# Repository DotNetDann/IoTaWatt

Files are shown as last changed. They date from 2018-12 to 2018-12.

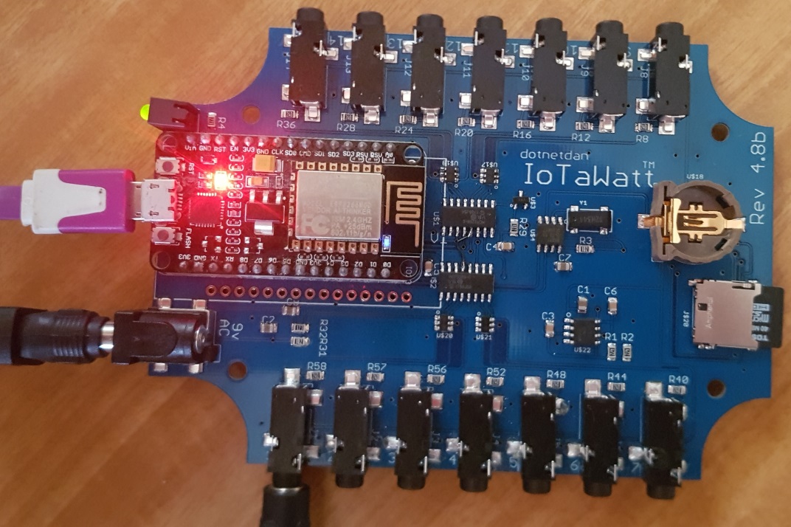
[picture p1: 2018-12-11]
PCB.jpg

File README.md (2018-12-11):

### IotaWatt 4.8

This is forked from [boblemaire's github](https://github.com/boblemaire/IoTaWatt)

Changes to main repository:
* Changed the PCB to fit a ESP32 (In case one day) and to get the silk screen to show in the generated gurbers
* Created a sample config to integrate with HomeAssistant. This integration uses the rest sensor in HA and query’s the JSON data every few seconds. You are able to get all your channels as well as any output calculated values you have setup.

NOTE: The PCB s using a 1v refrence shunt so you need to edit the config.txt to add a refvolts item under the device.

>{
>	"device": {
>		"refvolts": 1.0,

Go to the main repository as boblemaire is doing some amazing work with this project.

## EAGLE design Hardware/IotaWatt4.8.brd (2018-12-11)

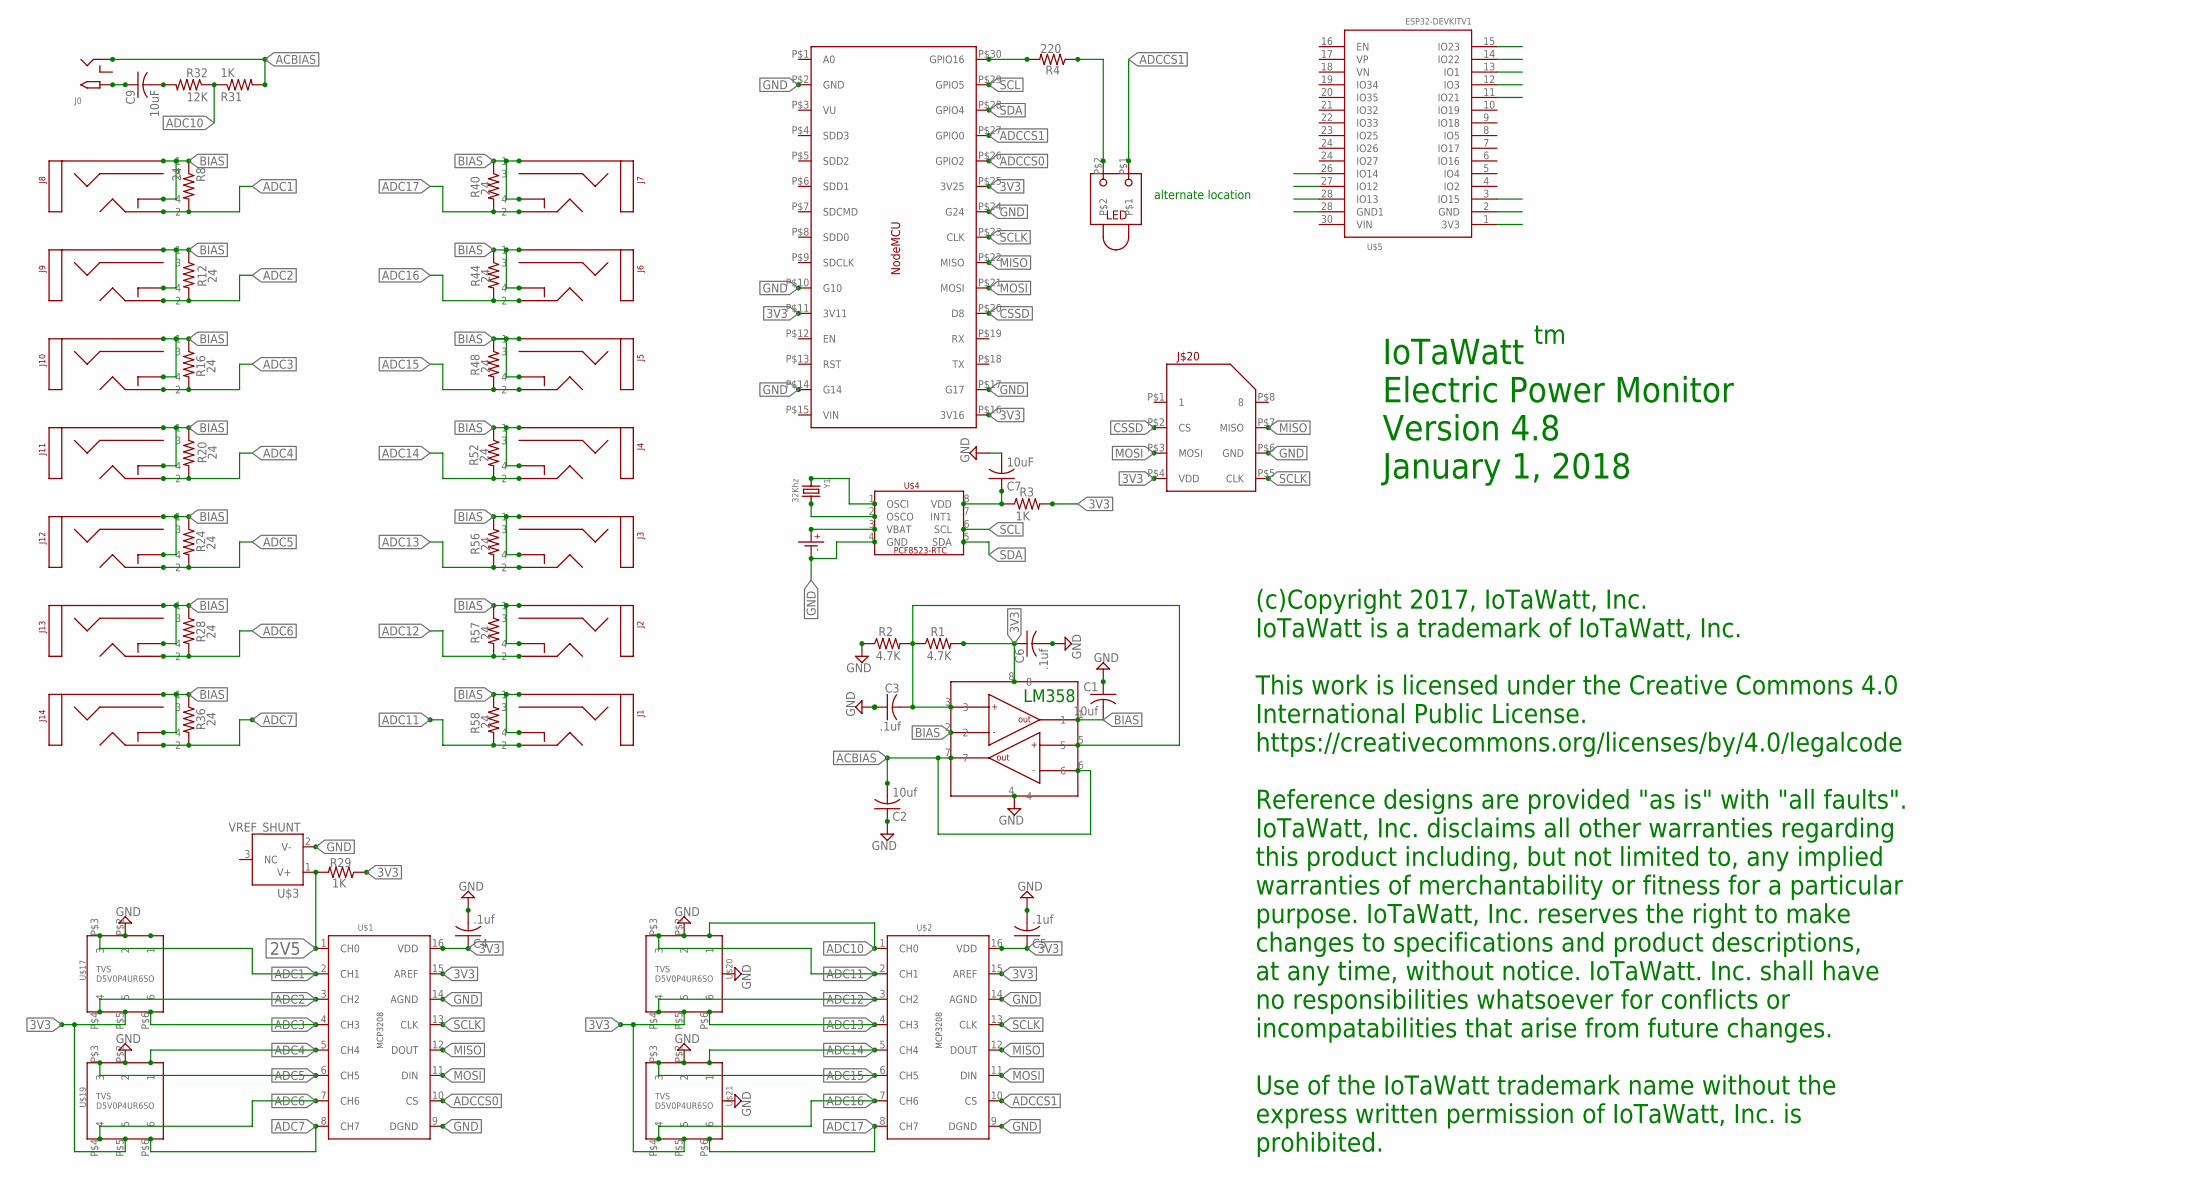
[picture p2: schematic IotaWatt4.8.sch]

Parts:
C1, C2: 10uf; C0805
C3, C4, C5, C6: .1uf; C0805
C7, C9: 10uF; C0805
J0: 2.1MMJACKSMT; DCJACK_2MM_SMT
J1, J2, J3, J4, J5, J6, J7, J8, J9, J10, J11, J12, J13, J14: STEREO_SMD; STEREO_SMT
J$20: MICROSD_PUSH/PULL; MICROSD
R1, R2: 4.7K; R0805
R3, R29, R31: 1K; R0805
R4: 220; R0805
R8, R12, R16, R20, R24, R28, R36, R40, R44, R48, R52, R56, R57, R58: 24; R0805
R32: 12K; R0805
U$1, U$2: MCP3208; SOIC_16
U$3: VREF_SHUNT; SOT23_3
U$4: PCF8523_RTC; SOIC_8
U$5: ESP32DEVKITV1; ESP32-DEVKITV1
U$16: NODEMCU
U$17, U$19, U$20, U$21: TVS_4CHAN_ARRAYSC-74; SC-74
U$18: CR1220SMD
U$22: LM358_DUAL_OP-AMP; SOIC_8
U$23: LED_RT_TRH; LED_TH_RT
Y1: 32Khz; CRYSTAL_8X3.8

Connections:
2V5: R29.2, U$1.1 (CH0), U$3.1 (V+)
3V3: C4.1, C5.1, C6.1, J$20.P$4 (VDD), R1.2, R3.2, R29.1, U$1.15 (AREF), U$1.16 (VDD), U$2.15 (AREF), U$2.16 (VDD), U$5.1 (3V3), U$16.P$11 (3V11), U$16.P$16 (3V16), U$16.P$25 (3V25), U$17.P$5 (5), U$19.P$5 (5), U$20.P$5 (5), U$21.P$5 (5), U$22.8
ACBIAS: C2.2, J0.GND (RING), R31.2, U$22.6, U$22.7
ADC1: J8.P$2 (2), R8.2, U$1.2 (CH1), U$17.P$3 (3)
ADC2: J9.P$2 (2), R12.2, U$1.3 (CH2), U$17.P$4 (4)
ADC3: J10.P$2 (2), R16.2, U$1.4 (CH3), U$17.P$6 (6)
ADC4: J11.P$2 (2), R20.2, U$1.5 (CH4), U$19.P$1 (1)
ADC5: J12.P$2 (2), R24.2, U$1.6 (CH5), U$19.P$3 (3)
ADC6: J13.P$2 (2), R28.2, U$1.7 (CH6), U$19.P$4 (4)
ADC7: J14.P$2 (2), R36.2, U$1.8 (CH7), U$19.P$6 (6)
ADC10: R31.1, R32.1, U$2.1 (CH0), U$20.P$1 (1)
ADC11: J1.P$2 (2), R58.2, U$2.2 (CH1), U$20.P$3 (3)
ADC12: J2.P$2 (2), R57.2, U$2.3 (CH2), U$20.P$4 (4)
ADC13: J3.P$2 (2), R56.2, U$2.4 (CH3), U$20.P$6 (6)
ADC14: J4.P$2 (2), R52.2, U$2.5 (CH4), U$21.P$1 (1)
ADC15: J5.P$2 (2), R48.2, U$2.6 (CH5), U$21.P$3 (3)
ADC16: J6.P$2 (2), R44.2, U$2.7 (CH6), U$21.P$4 (4)
ADC17: J7.P$2 (2), R40.2, U$2.8 (CH7), U$21.P$6 (6)
ADCCS0: U$1.10 (CS), U$5.11 (IO21), U$16.P$26 (GPIO2)
ADCCS1: U$2.10 (CS), U$5.12 (IO3), U$16.P$27 (GPIO0), U$23.P$1
BIAS: C1.2, J1.P$1 (1), J1.P$4 (4), J2.P$1 (1), J2.P$4 (4), J3.P$1 (1), J3.P$4 (4), J4.P$1 (1), J4.P$4 (4), J5.P$1 (1), J5.P$4 (4), J6.P$1 (1), J6.P$4 (4), J7.P$1 (1), J7.P$4 (4), J8.P$1 (1), J8.P$4 (4), J9.P$1 (1), J9.P$4 (4), J10.P$1 (1), J10.P$4 (4), J11.P$1 (1), J11.P$4 (4), J12.P$1 (1), J12.P$4 (4), J13.P$1 (1), J13.P$4 (4), J14.P$1 (1), J14.P$4 (4), R8.1, R12.1, R16.1, R20.1, R24.1, R28.1, R36.1, R40.1, R44.1, R48.1, R52.1, R56.1, R57.1, R58.1, U$22.1, U$22.2
CSSD: J$20.P$2 (CS), U$5.3 (IO15), U$16.P$20 (D8)
LED: R4.2, U$5.15 (IO23), U$16.P$30 (GPIO16)
MISO: J$20.P$7 (MISO), U$1.12 (DOUT), U$2.12 (DOUT), U$5.27 (IO12), U$16.P$22 (MISO)
unnamed: C7.1, R3.1, U$4.8 (VDD)
unnamed: R4.1, U$23.P$2
unnamed: C9.2, R32.2
unnamed: C9.1, J0.PWR2 (TIP)
unnamed: U$4.3 (VBAT), U$18.P+ (P$+)
unnamed: U$4.2 (OSCO), Y1.P$4 (2)
unnamed: U$4.1 (OSCI), Y1.P$1 (1)
SCL: U$4.6 (SCL), U$5.14 (IO22), U$16.P$29 (GPIO5)
SCLK: J$20.P$5 (CLK), U$1.13 (CLK), U$2.13 (CLK), U$5.26 (IO14), U$16.P$23 (CLK)
SDA: U$4.5 (SDA), U$5.13 (IO1), U$16.P$28 (GPIO4)
VREF: C3.2, R1.1, R2.2, U$22.3, U$22.5

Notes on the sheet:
IoTaWatt Electric Power Monitor Version 4.8 January 1, 2018
alternate location
LM358
(c)Copyright 2017, IoTaWatt, Inc. IoTaWatt is a trademark of IoTaWatt, Inc. This work is licensed under the Creative Commons 4.0 International Public License. https://creativecommons.org/licenses/by/4.0/legalcode Reference designs are provided "as is" with "all faults". IoTaWatt, Inc. disclaims all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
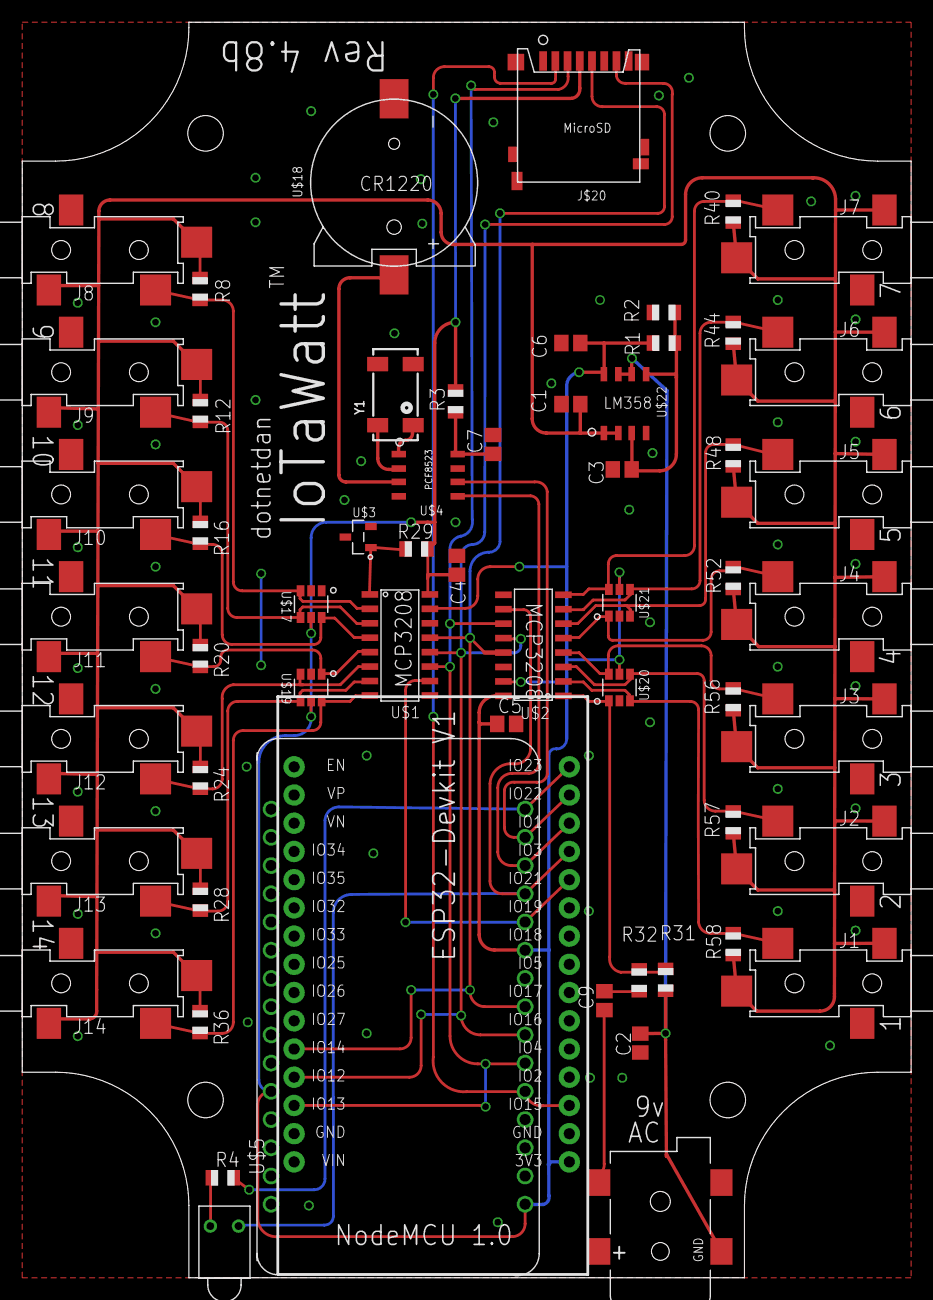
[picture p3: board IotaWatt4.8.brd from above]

Board: 2 copper layers, 80.0 x 113.0 mm, 59 parts (0 on the bottom side), 37 nets.

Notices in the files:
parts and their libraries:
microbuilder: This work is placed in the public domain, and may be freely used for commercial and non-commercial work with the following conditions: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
